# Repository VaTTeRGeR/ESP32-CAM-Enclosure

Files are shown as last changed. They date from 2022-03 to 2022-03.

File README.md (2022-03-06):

# ESP32-CAM-Enclosure
Compact enclosure for the ubiquitous ESP32-CAM with the USB-Serial board and an external antenna. The program- and reset-button are still accessible through the cooling slits.

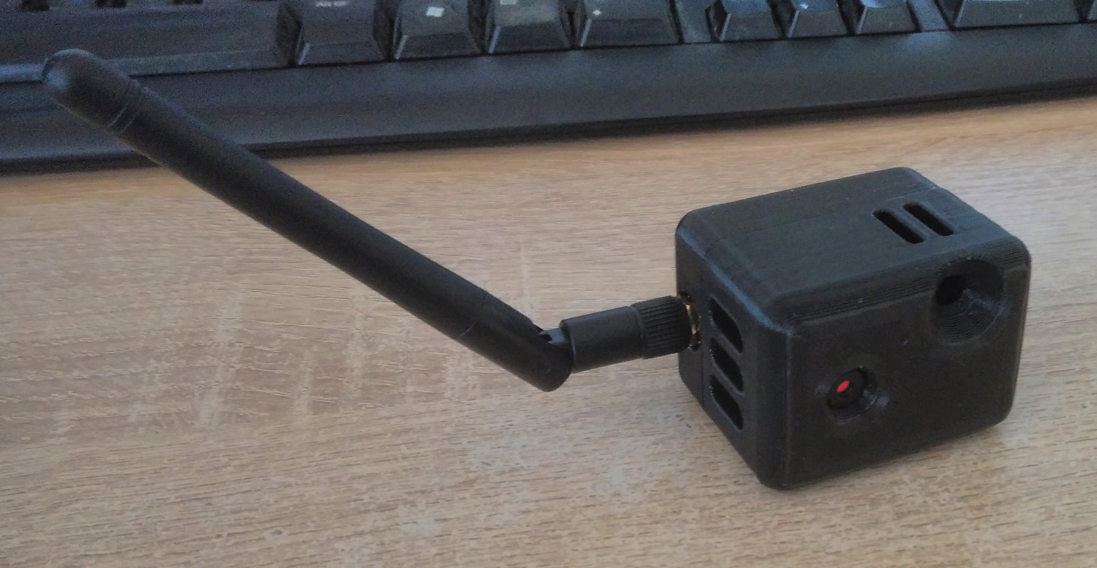
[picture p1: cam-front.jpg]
Photo Front


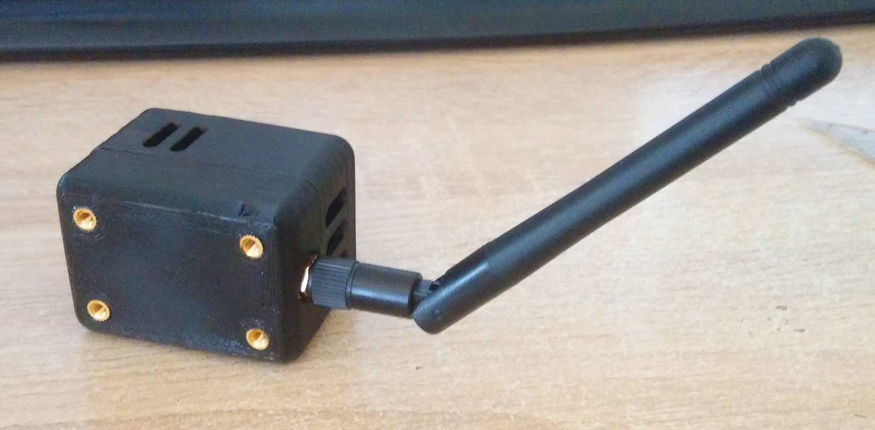
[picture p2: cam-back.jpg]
Photo Back


# Mounting Points
The holes in the bottom piece are laid out in a 34x21mm rectangle. They are sized for M3-5x5mm threaded inserts.

# Printing Guide
Use the combined *.stl file for easy printing. Print time is 3 hours with average printing speeds and 100% infill. Support should not be necessary if your cooling is sufficient.

# Additional Materials
1. Glue (Cyanacrylate aka Super Glue is recommended)
2. Optional: Threaded inserts M3-5x5mm

# Assembly
1. Insert the ESP32-CAM into the front piece, guiding the antenna cable through the small gap on the side of the enclosure.
2. Screw the SMA-Connector to the bottom piece and wind the excess antenna cable into a loop.
3. Test fit the two halves, then glue together with super glue once everything fits. The two halves are self aligning.
4. Melt the threaded inserts into their holes in the back if you need mounting points. The holes are sized for the cheap M3-5x5mm threaded inserts.

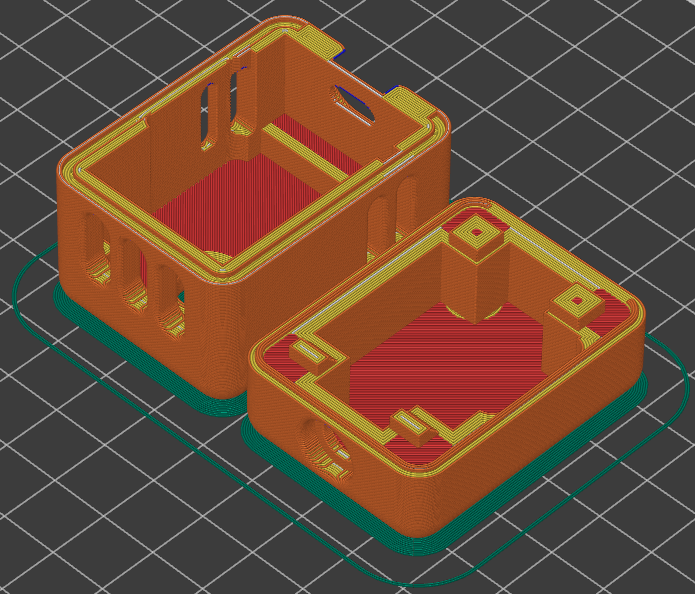
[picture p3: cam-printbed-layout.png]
Printing Layout


# CAD Screenshots

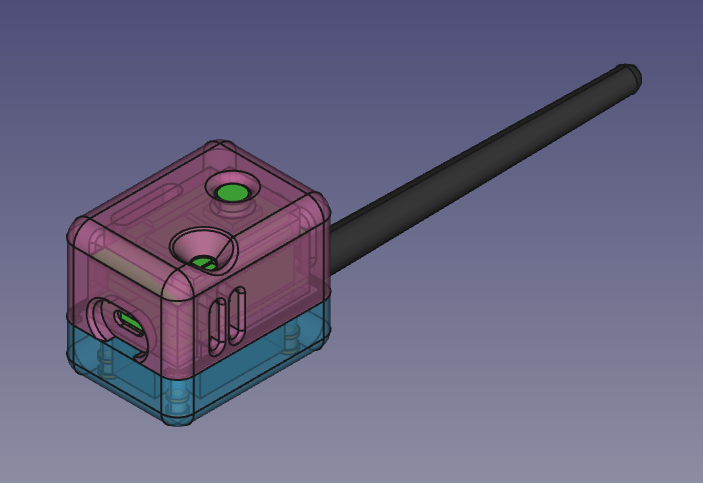
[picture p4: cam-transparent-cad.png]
CAD View Transparent


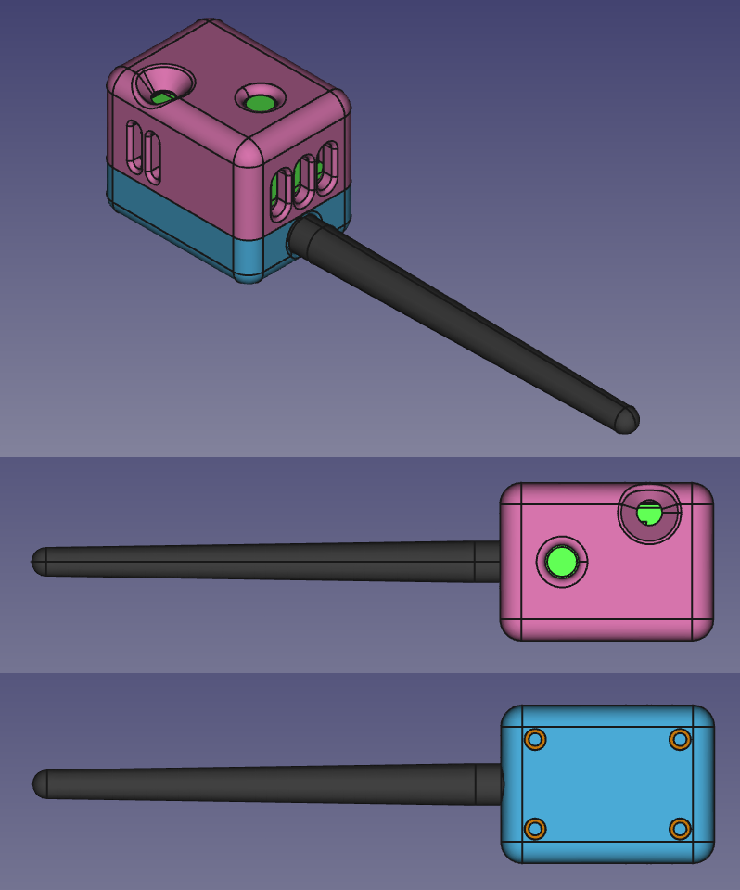
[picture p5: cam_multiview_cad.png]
CAD View


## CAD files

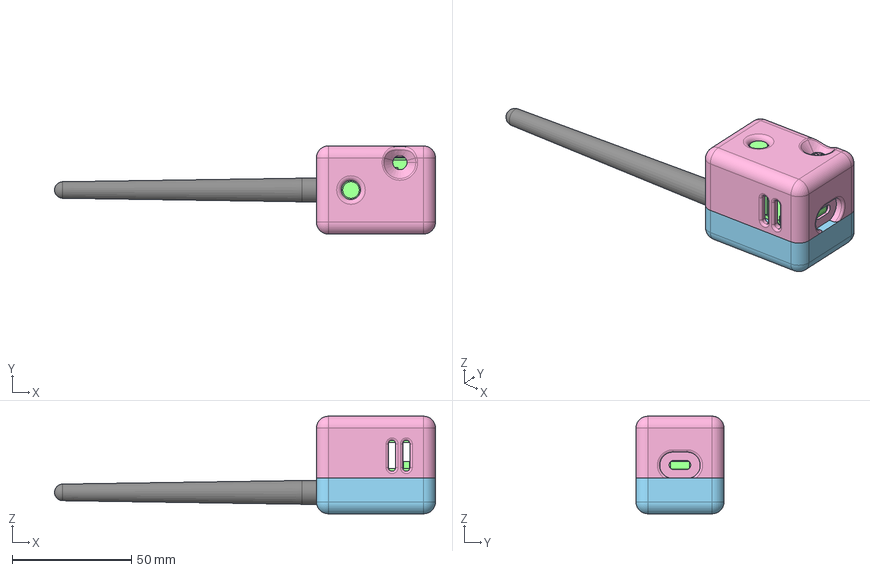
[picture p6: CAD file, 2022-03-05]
esp32-cam-shell.FCStd
160.0 x 37.0 x 41.0 mm
pcb-main
sma-female
m3-insert-5x5-001
m3-insert-5x5-002
m3-insert-5x5-003
m3-insert-5x5-004
shell-front
shell-back

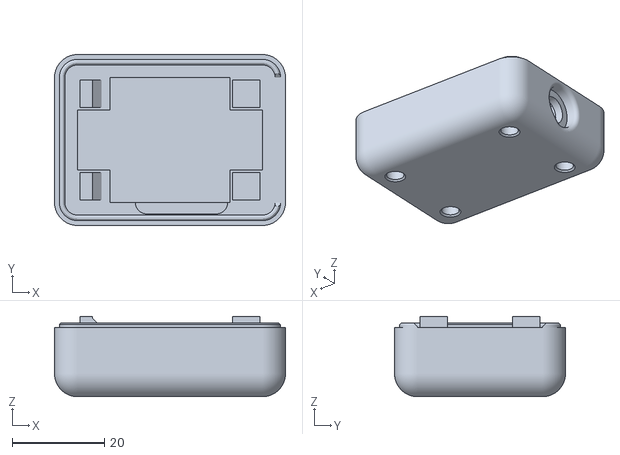
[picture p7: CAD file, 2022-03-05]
esp32-cam-shell-back.stl
50.0 x 37.0 x 17.4

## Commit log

2022-03-05 Initial commit.
    [esp32-cam-shell-back.stl, esp32-cam-shell.FCStd]
2022-03-05 Added printing layout image
